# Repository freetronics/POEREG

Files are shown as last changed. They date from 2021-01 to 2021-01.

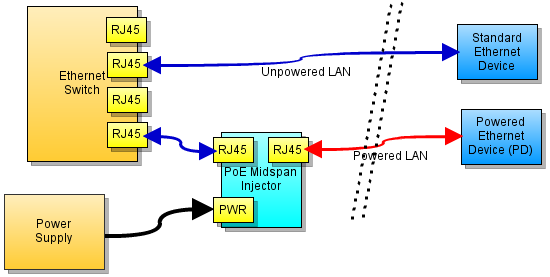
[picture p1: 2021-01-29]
Docs/poe-architecture.png

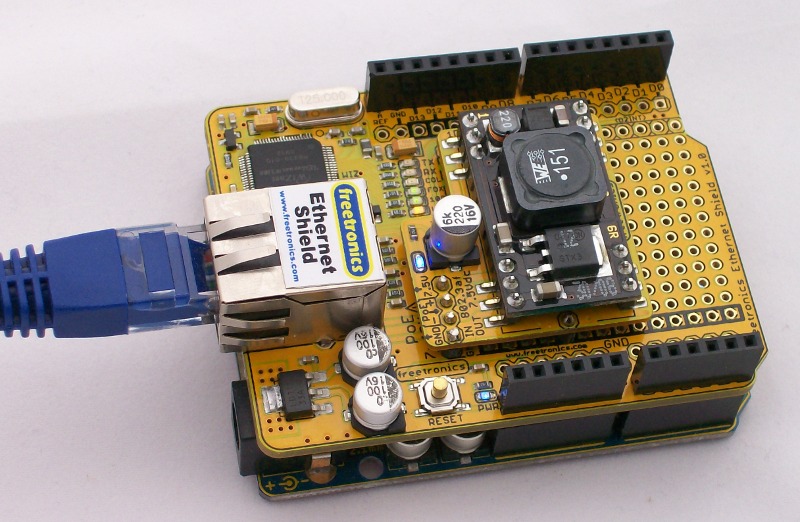
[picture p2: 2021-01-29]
Images/reg8023-operating-800.jpg

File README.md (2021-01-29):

Power-over-Ethernet 802.3af Regulator
=====================================

Module to regulate power supplied on Power-over-Ethernet connection
down to 10Vdc for supply to the on-board voltage regulator in an
Arduino Uno or other compatible board using the Freetronics Ethernet
Shield, or boards with onboard Ethernet such as the Freetronics
EtherTen, EtherMega, and EtherDue.

The output can optionally be switched to 12V which can be useful for
supplying power to external loads such as 12V relays.

Features:

 * Adds 802.3af-compliant Power-over-Ethernet "PD" (powered device)
   support to the Freetronics Ethernet shield and other Freetronics
   boards.
 * Input voltage range 36-57Vdc (nominal 48Vdc for 802.3af PoE)
 * Output voltage regulated to 10V and fed to Arduino on-board voltage
   regulator via Ethernet shield for further regulation down to 5V.
 * Plugs directly onto Freetronics Ethernet Shield and other
   Freetronics boards.
 * "Power on" LED.

More information at:

  http://www.freetronics.com.au/poereg

Hardware
--------
The "Hardware" directory contains the PCB design as an EAGLE project.
EAGLE PCB design software is available from Autodesk free for
non-commercial use.

Credits
-------
  * Jonathan Oxer <jon@oxer.com.au>

License
-------
Copyright 2010-2021 Freetronics Pty Ltd www.freetronics.com

The hardware portion of this project is licensed under the TAPR Open
Hardware License (www.tapr.org/OHL). The "license" folder within this
repository also contains a copy of this license in plain text format.

The software portion of this project is licensed under the Simplified
BSD License. The "licence" folder within this project contains a
copy of this license in plain text format.

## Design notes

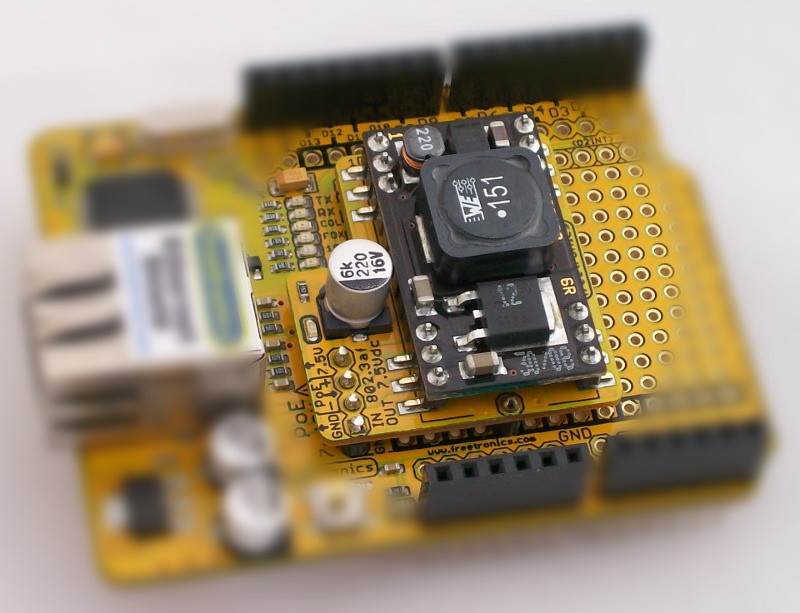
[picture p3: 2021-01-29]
Images/reg8023-inplace.jpg

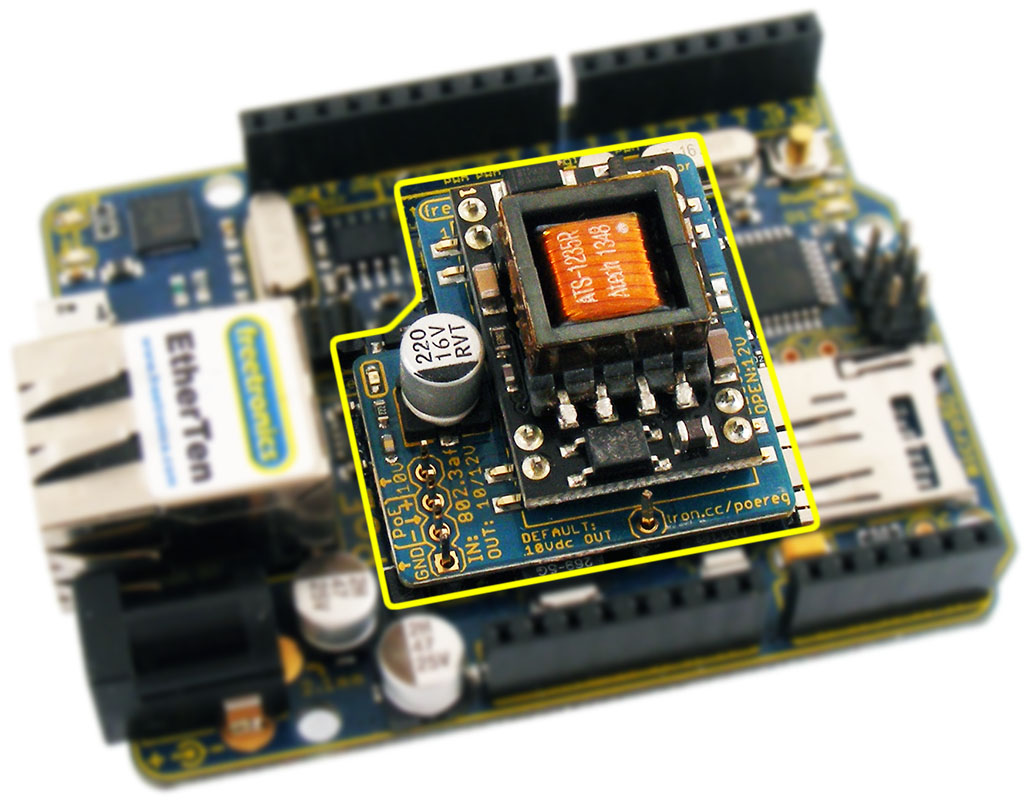
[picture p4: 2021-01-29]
Images/REG8023AF-v2_0-fitted-blurred.jpg

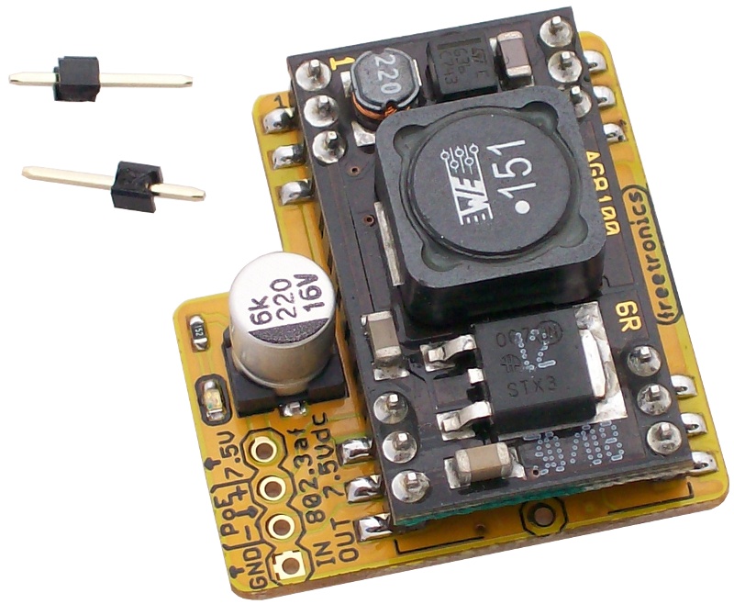
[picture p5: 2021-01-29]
Images/reg8023-oblique-800.jpg

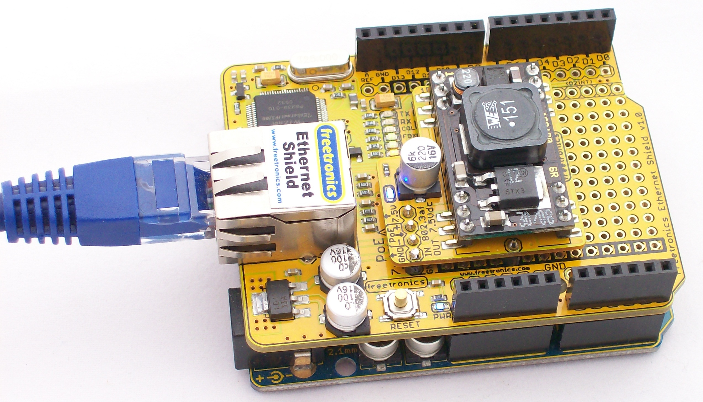
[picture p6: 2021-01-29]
Images/reg8023-fitted.jpg

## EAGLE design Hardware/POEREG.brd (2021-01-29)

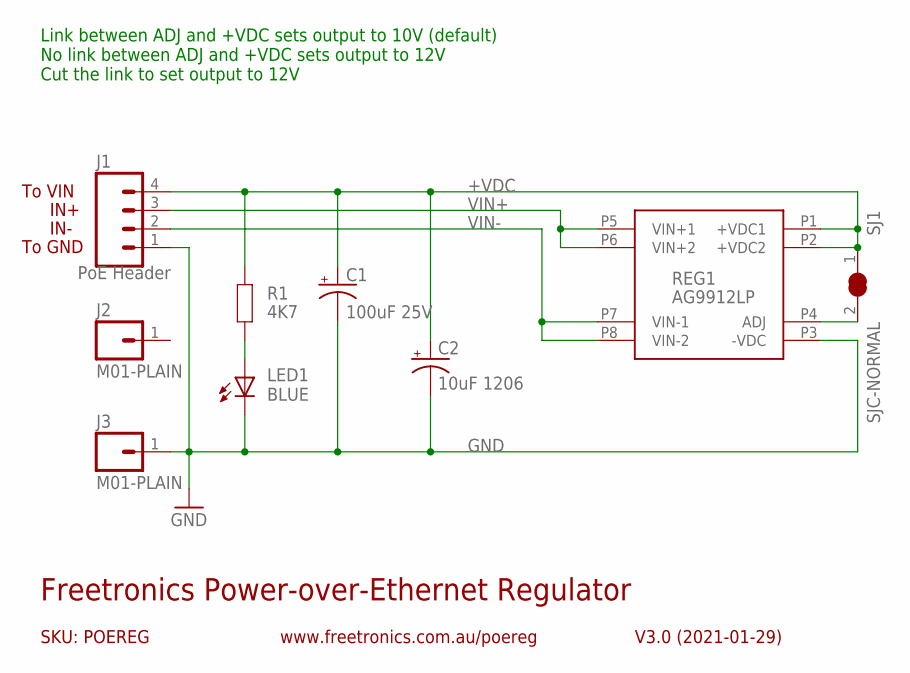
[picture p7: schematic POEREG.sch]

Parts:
C1: 100uF 25V; PANASONIC_D
C2: 10uF 1206; EIA3216
J1: PoE Header; 1X04
J2, J3: M01-PLAIN; 1X01
LED1: BLUE; LED-0603
R1: 4K7; R0603
REG1: AG9912LP; AG9900LP
SJ1: SJC-NORMAL; SJC

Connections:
+VDC: C1.+, C2.A (+), J1.4, R1.1, REG1.P1 (+VDC1), REG1.P2 (+VDC2), SJ1.1
GND: C1.-, C2.C (-), J1.1, J3.1, LED1.C, REG1.P3 (-VDC)
unnamed: REG1.P4 (ADJ), SJ1.2
unnamed: LED1.A, R1.2
VIN+: J1.3, REG1.P5 (VIN+1), REG1.P6 (VIN+2)
VIN-: J1.2, REG1.P7 (VIN-1), REG1.P8 (VIN-2)

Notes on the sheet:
Freetronics Power-over-Ethernet Regulator
V3.0 (2021-01-29)
www.freetronics.com.au/poereg
SKU: POEREG
To VIN
IN+
IN-
To GND
Link between ADJ and +VDC sets output to 10V (default) No link between ADJ and +VDC sets output to 12V Cut the link to set output to 12V

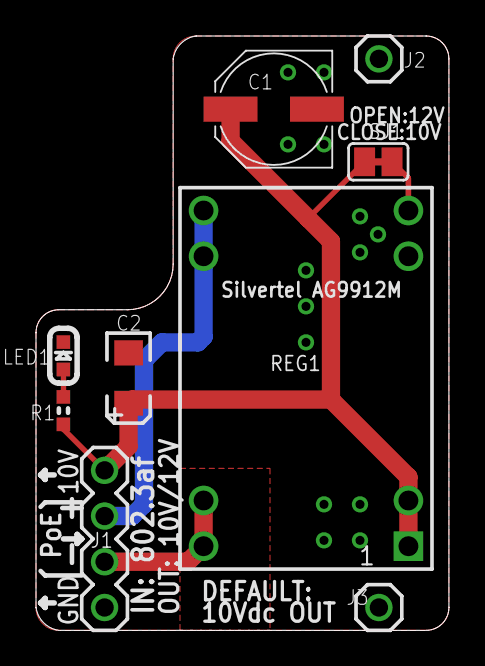
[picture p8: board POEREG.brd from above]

Board: 2 copper layers, 22.9 x 33.0 mm, 9 parts (0 on the bottom side), 6 nets.

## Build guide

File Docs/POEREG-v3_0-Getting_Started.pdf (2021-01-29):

## PoE Regulator 802.3af v3.0

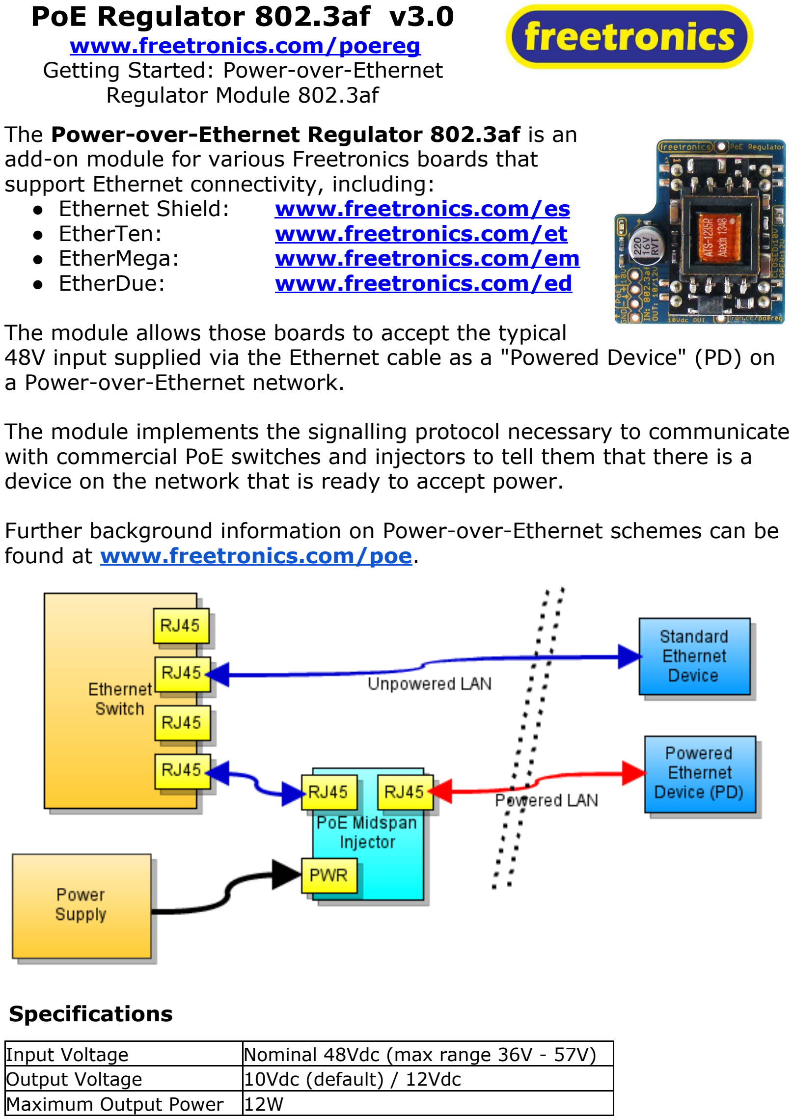
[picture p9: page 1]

The Power-over-Ethernet Regulator 802.3af is an add-on module for various Freetronics boards that support Ethernet connectivity, including:
- Ethernet Shield: | www.freetronics.com/es
- EtherTen: | www.freetronics.com/et
- EtherMega: | www.freetronics.com/em
- EtherDue: | www.freetronics.com/ed

The module allows those boards to accept the typical
48V input supplied via the Ethernet cable as a "Powered Device" (PD) on a Power-over-Ethernet network.

The module implements the signalling protocol necessary to communicate with commercial PoE switches and injectors to tell them that there is a device on the network that is ready to accept power.

Further background information on Power-over-Ethernet schemes can be found at www.freetronics.com/poe.

Specifications

www.freetronics.com/poereg Getting Started: Power-over-Ethernet Regulator Module 802.3af

Input Voltage | Nominal 48Vdc (max range 36V - 57V)
Output Voltage | 10Vdc (default) / 12Vdc
Maximum Output Power | 12W

Installation

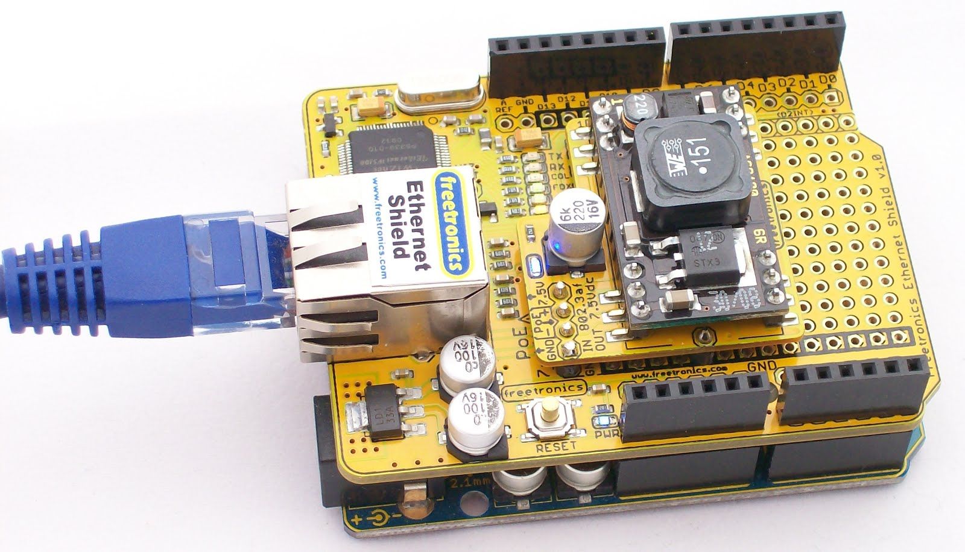
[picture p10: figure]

### 1. Remove the jumpers from the PoE header on your Arduino compatible board or

shield if they are fitted.

### 2. Place the single-pin headers into the mounting holes on the module, with the pins

extending down.

### 3. Place the PoE Regulator 802.3af onto the host board. You can use a piece of

cardboard as a temporary spacer to hold the module above any other parts on the board it until it has been soldered in place. On the Ethernet Shield, the single-pin headers fit into the 5V and GND rails.

### 4. Solder all the header pins to the top of the regulator. Turn over and solder the

single-pin headers on the bottom. Trim off any excess length.
5. Connect your host board to your Ethernet network.

### 6. Connect the network segment to Power Sourcing Equipment such as a PoE switch

or midspan injector.
Changing Output Voltage

The PoE Regulator 802.3af has a default output of 10V. You can increase the output voltage to 12V if required, such as for powering external 12V loads via the VIN connection on the Arduino. Use a sharp knife or scalpel to carefully cut the tiny track between the solder pads on the top of the module to set the output to 12V. If you later wish to return the output to 10V, you can bridge across the pads with a blob of solder.
Support

For assistance see www.freetronics.com/support or forum.freetronics.com, or email support@freetronics.com.

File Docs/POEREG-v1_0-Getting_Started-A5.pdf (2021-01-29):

## PoE Regulator 802.3af

www.freetronics.com/poe-regulator-8023af

## Getting Started: Power-over-Ethernet Regulator 802.3af

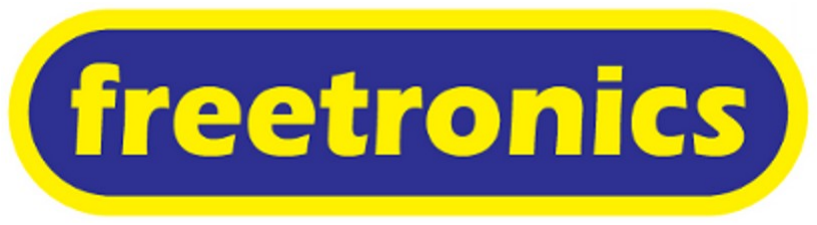
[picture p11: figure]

The Power-over-Ethernet Regulator 802.3af is an add-on board for the Freetronics Ethernet Shield (www.freetronics.com/ethernet-shield) and Freetronics EtherTen (www.freetronics.com/etherten) that allows them to accept the 48V input supplied via the Ethernet cable as a "Powered Device" (PD) on a Power-over-Ethernet network.

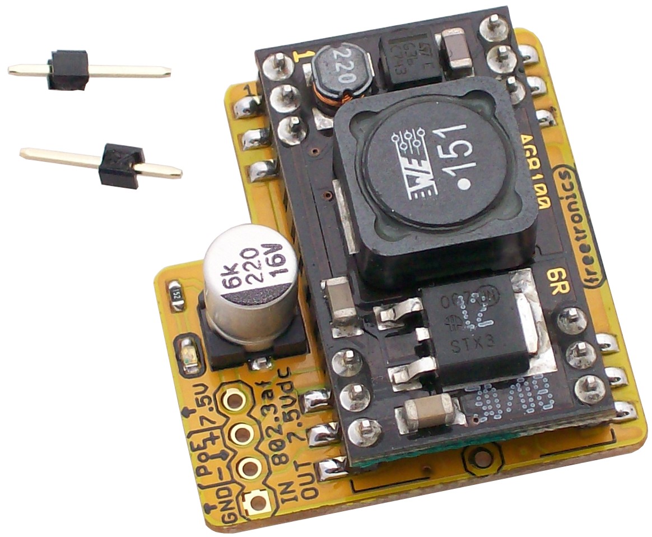
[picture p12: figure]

The module implements the signalling
protocol necessary to communicate with
commercial PoE switches and injectors to tell them that there is a device on the network that is ready to accept power, and then uses an efficient switch-mode regulator to reduce the voltage to 7.5V for supply to the host's onboard voltage regulator.

Further background information on Power-over-Ethernet schemes can be found at www.freetronics.com/poe

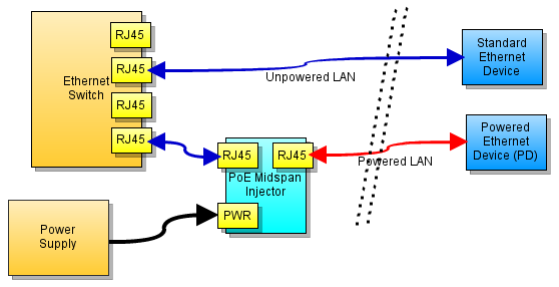
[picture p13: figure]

## Specifications

Input Voltage: | Nominal 48Vdc
Output Voltage: | 7.5Vdc
Maximum Power: | 12W

1

## Installation

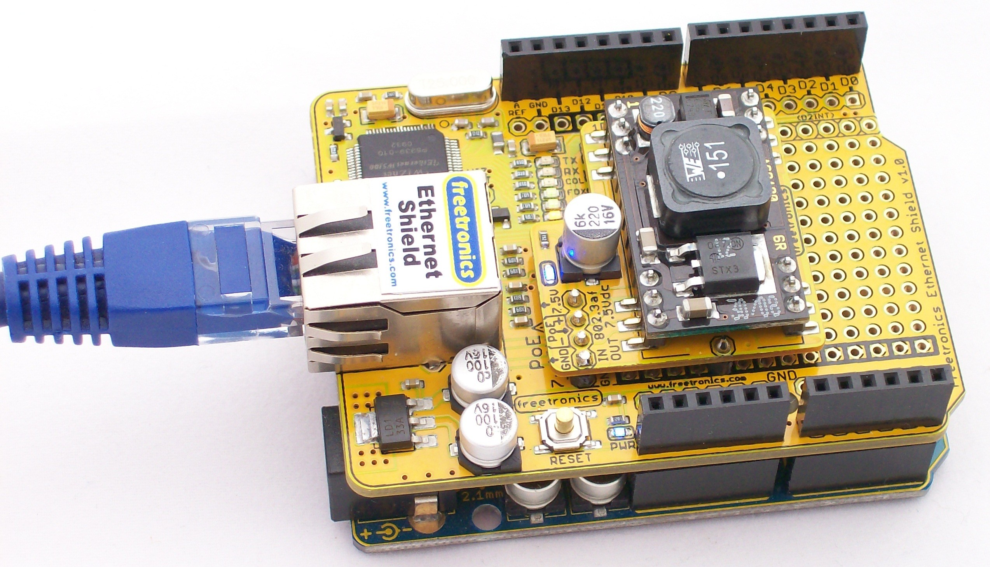
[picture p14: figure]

### 1. Remove the jumpers from the PoE header pins on your Ethernet Shield or

EtherTen if they are fitted.

### 2. For an Ethernet Shield, place the provided single-pin headers into the GND

and 5V rails adjacent to the prototyping area so that they align with the centre holes in the PoE Regulator. For an EtherTen, place them in the holes provided.

### 3. Place the PoE Regulator onto the header pins. For an EtherTen, use a thick

piece of cardboard or similar as a spacer to hold it clear of the parts underneath. The cardboard can be removed later after the pins are soldered.

### 4. Solder the 6 header pins to the top of the regulator PCB. Clip off any excess

length.

### 5. Turn over the Ethernet Shield and solder the bottom of the single-pin

headers in place. Clip off any excess length.

### 6. For an Ethernet Shield, fit it to your Arduino. Plug the Ethernet Shield or

EtherTen into your Ethernet network.

### 7. Connect the network segment to Power Sourcing Equipment such as a PoE

switch or midspan injector.

## Support

For assistance see www.freetronics.com/support or email support@freetronics.com.

## About Freetronics

Freetronics is an Australian company created by Jonathan Oxer and Marc Alexander to provide easy access to hardware, parts, and products related to Arduino projects and the book Practical Arduino. Learn more at www.freetronics.com. Follow us on Twitter at twitter.com/freetronics.

2

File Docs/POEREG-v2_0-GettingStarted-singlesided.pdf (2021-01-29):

# PoE Regulator 802.3af v2.0

## www.freetronics.com/poereg

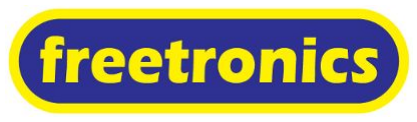
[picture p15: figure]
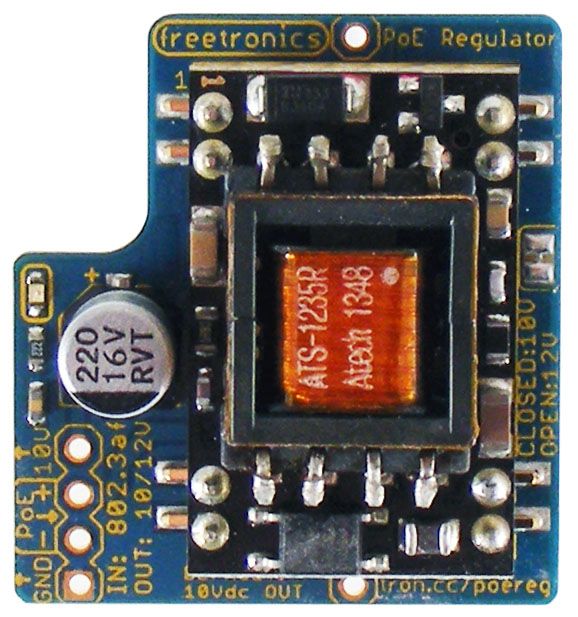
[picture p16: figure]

The Powerover-Ethernet Regulator 802.3af is an addon module for various Freetronics boards that support Ethernet connectivity, including:
- Ethernet Shield: | www.freetronics.com/es
- EtherTen: | www.freetronics.com/et
- EtherMega: | www.freetronics.com/em
- EtherDue: | www.freetronics.com/ed

The module allows those boards to accept the typical 48V input supplied via the Ethernet cable as a "Powered Device" (PD) on a Powerover-Ethernet network.

The module implements the signalling protocol necessary to communicate with commercial PoE switches and injectors to tell them that there is a device on the network that is ready to accept power.

Further background information on Powerover-Ethernet schemes can be found at www.freetronics.com/poe.

### Specifications

Input Voltage | Nominal 48Vdc (max range 36V 57V)
Output Voltage | 10Vdc (default) / 12Vdc
Maximum Output Power | 12W

### Installation

1. Remove the jumpers from the
PoE header on your Arduino compatible board or shield if they are fitted.
2. Place the singlepin headers into the mounting holes on the module, with the pins extending down.
3. Place the PoE Regulator 802.3af onto the host board. You can use a piece of cardboard as a temporary spacer to hold the module above any other parts on the board it until it has been soldered in place. On the Ethernet
Shield, the singlepin headers fit
into the 5V and GND rails.


4. Solder all the header pins to the top of the regulator. Turn over and solder the singlepin headers on the bottom. Trim off any excess length.
5. | Connect your host board to your Ethernet network.
6. | Connect the network segment to Power Sourcing Equipment such as a PoE switch or midspan
injector.

### Changing Output Voltage

The PoE Regulator 802.3af has a default output of 10V. You can increase the output voltage to 12V if required, such as for powering external 12V loads via the VIN connection on the Arduino. Use a sharp knife or scalpel to carefully cut the tiny track between the solder pads on the right side of the module to set the output to 12V. If you later wish to return the output to 10V, you can bridge across the pads with a blob of solder.

### Support

For assistance see www.freetronics.com/support or forum.freetronics.com, or email support@freetronics.com.

Follow us on Twitter at twitter.com/freetronics.

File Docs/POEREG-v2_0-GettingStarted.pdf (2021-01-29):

## PoE Regulator 802.3af v2.0

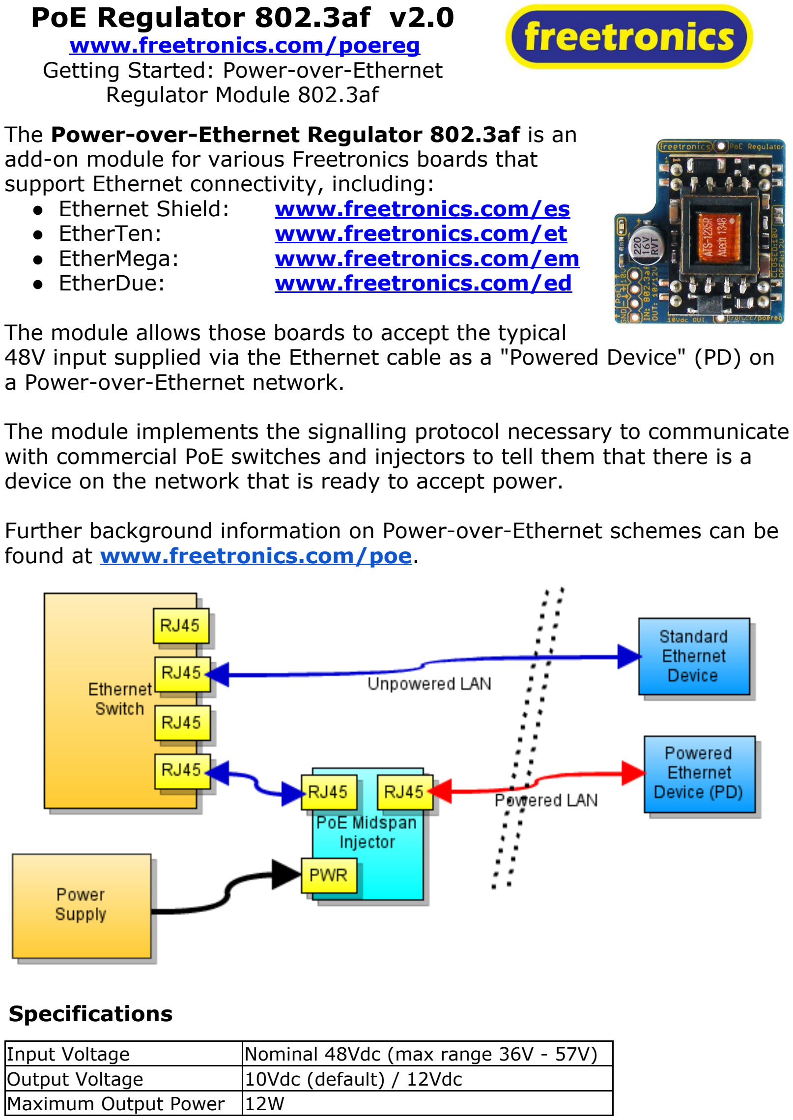
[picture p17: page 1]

www.freetronics.com/poereg Getting Started: Powerover-Ethernet
Regulator Module 802.3af
The Powerover-Ethernet Regulator 802.3afis an addon module for various Freetronics boards that support Ethernet connectivity, including:
- Ethernet Shield: | www.freetronics.com/es
- EtherTen: | www.freetronics.com/et
- EtherMega: | www.freetronics.com/em
- EtherDue: | www.freetronics.com/ed

The module allows those boards to accept the typical
48V input supplied via the Ethernet cable as a "Powered Device" (PD) on a Powerover-Ethernet network.

The module implements the signalling protocol necessary to communicate with commercial PoE switches and injectors to tell them that there is a device on the network that is ready to accept power.

Further background information on Powerover-Ethernet schemes can be found at www.freetronics.com/poe.

Specifications

Input Voltage | Nominal 48Vdc (max range 36V 57V)
Output Voltage | 10Vdc (default) / 12Vdc
Maximum Output Power | 12W

Installation

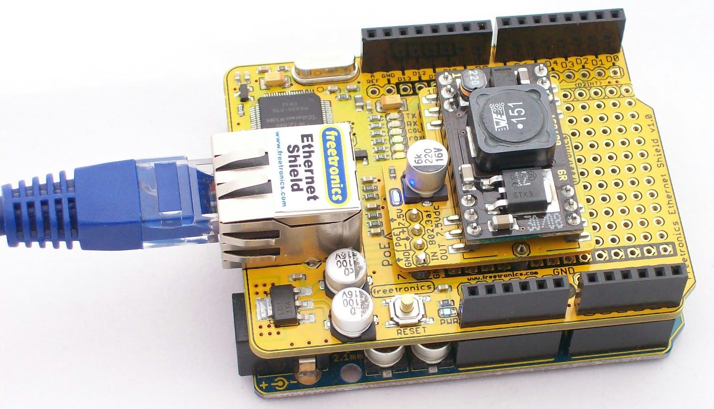
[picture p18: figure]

1. Remove the jumpers from the PoE header on your Arduino compatible board or shield if they are fitted.
2. Place the singlepin headers into the mounting holes on the module, with the pins extending down.
3. Place the PoE Regulator 802.3afonto the host board. You can use a piece of cardboard as a temporary spacer to hold the module above any other parts on the board it until it has been soldered in place. On the Ethernet Shield, the singlepin headers fit into the 5V and GND rails.
4. Solder all the header pins to the top of the regulator. Turn over and solder the singlepin headers on the bottom. Trim off any excess length.
5.Connect your host board to your Ethernet network.
6.Connect the network segment to Power Sourcing Equipment such as a PoE switch or midspan injector.
Changing Output Voltage

The PoE Regulator 802.3af has a default output of 10V. You can increase the output voltage to 12V if required, such as for powering external 12V loads via the VIN connection on the Arduino. Use a sharp knife or scalpel to carefully cut the tiny track between the solder pads on the right side of the module to set the output to 12V. If you later wish to return the output to 10V, you can bridge across the pads with a blob of solder.
Support

For assistance see www.freetronics.com/supportor forum.freetronics.com, or email support@freetronics.com.
About Freetronics

Freetronics is an Australian company created by Jonathan Oxer and Marc
Alexander to provide easy access to hardware, parts, and products related to Arduino projects and the book Practical Arduino. Learn more at www.freetronics.com. Follow us on Twitter at twitter.com/freetronics.

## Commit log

2010-07-28 Initial import of project
    [PoERegulator8023af.brd, PoERegulator8023af.sch]
2010-09-14 Updated reg part to have correct footprint
    [PoERegulator8023af.sch]
2010-09-14 Major board rearrangement, only partly done
    [PoERegulator8023af.brd]
2010-09-24 Changed output to 7.5V and finished routing
    [PoERegulator8023af.brd, PoERegulator8023af.sch]
2010-09-26 Final positioning tweaks
    [PoERegulator8023af.brd]
2010-10-05 Fixed reference to output voltage
2014-06-10 Added option to change output to 12V
    [PoERegulator8023af.brd, PoERegulator8023af.sch]
2014-06-11 Replaced Silvertel AG8112M with AG9812M for v2.0 release
    [PoERegulator8023af.brd, PoERegulator8023af.sch]
2016-05-26 Improved position of part value labels
    [PoERegulator8023af.brd]
2019-04-24 Fixed fonts for silkscreen and schematic
    [PoERegulator8023af.brd, PoERegulator8023af.sch]
2021-01-29 Renamed hardware files to match SKU.
    [POEREG.brd, POEREG.sch]
2021-01-29 Replace Silvertel module with AG9912LP.
    [POEREG.brd, POEREG.sch]
2021-01-29 Updated formatting to match current template.

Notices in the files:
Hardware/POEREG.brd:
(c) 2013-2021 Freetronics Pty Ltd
